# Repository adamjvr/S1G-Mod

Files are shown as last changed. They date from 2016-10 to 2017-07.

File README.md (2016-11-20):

# S1G-Mod
A Sub 1GHZ Wireless Module for various Sub 1GHZ projects and applications
Hardware Specs
- ADF7023 RF Transceiver
- 28 Mile line of site range
- Dedicated Antennas for RX and TX
- Open Source under CERN Open Hardware License v1.2 (Included)
- Circuitry shielded with outer shield.
- UM Coaxial Antenna connectors
- STM32L052C8T6 ARM Cortex M0+
- USB 2.0 connectivity
- USART connectivity
- SPI connectivity
- USB bus or battery powered
- Combined and Separate PA/LNA Match versions of 915MHZ and 433MHZ modules

Firmware and development at:
https://github.com/adamjvr/S1G-RF-firmwware

Combined RX/TX S1G-RF Module:
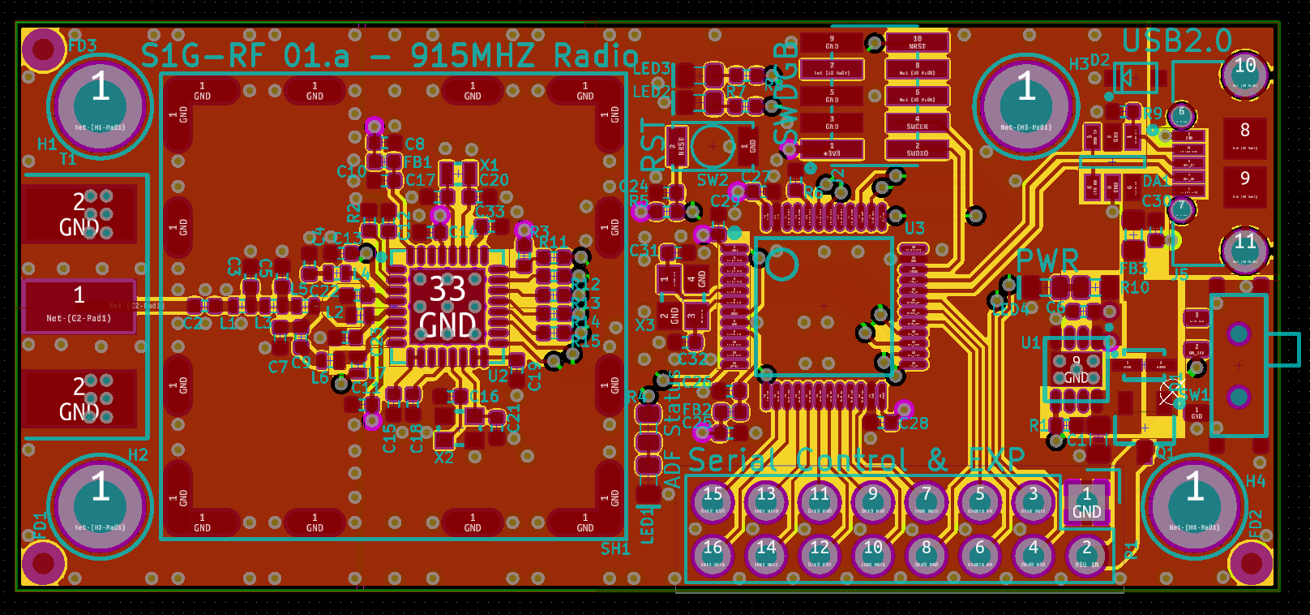
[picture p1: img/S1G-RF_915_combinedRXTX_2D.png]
Combined RX/TX S1G-RF

KiCAD 3D OpenGL
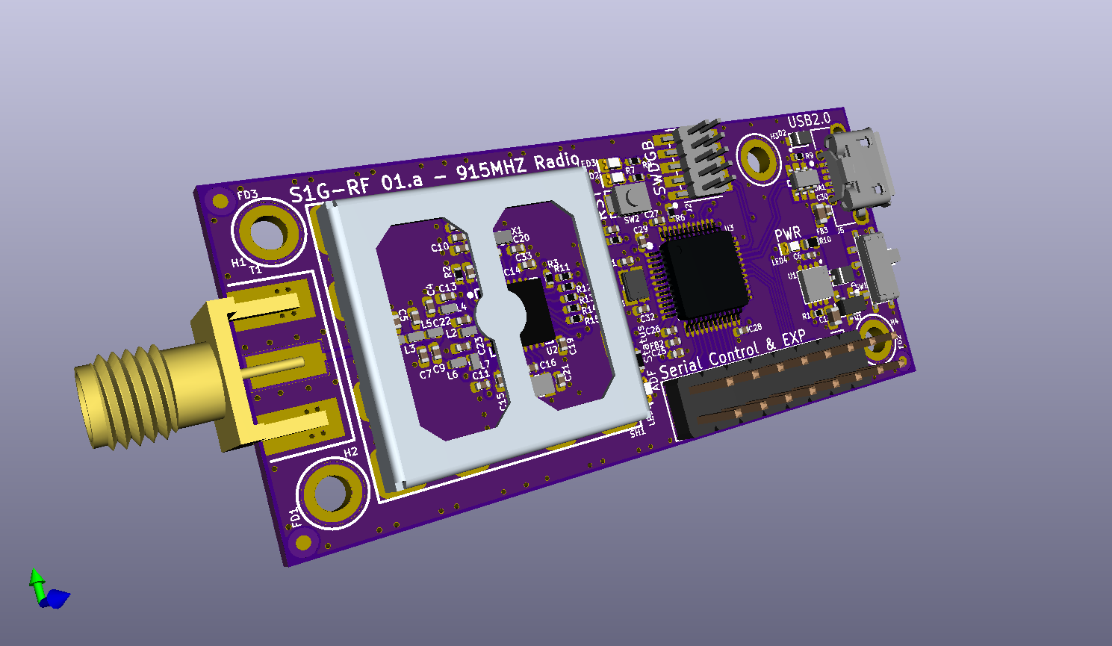
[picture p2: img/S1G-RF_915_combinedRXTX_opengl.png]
Combined RX/TX S1G-RF 3D


Separate RX/TX S1G-RF Module:
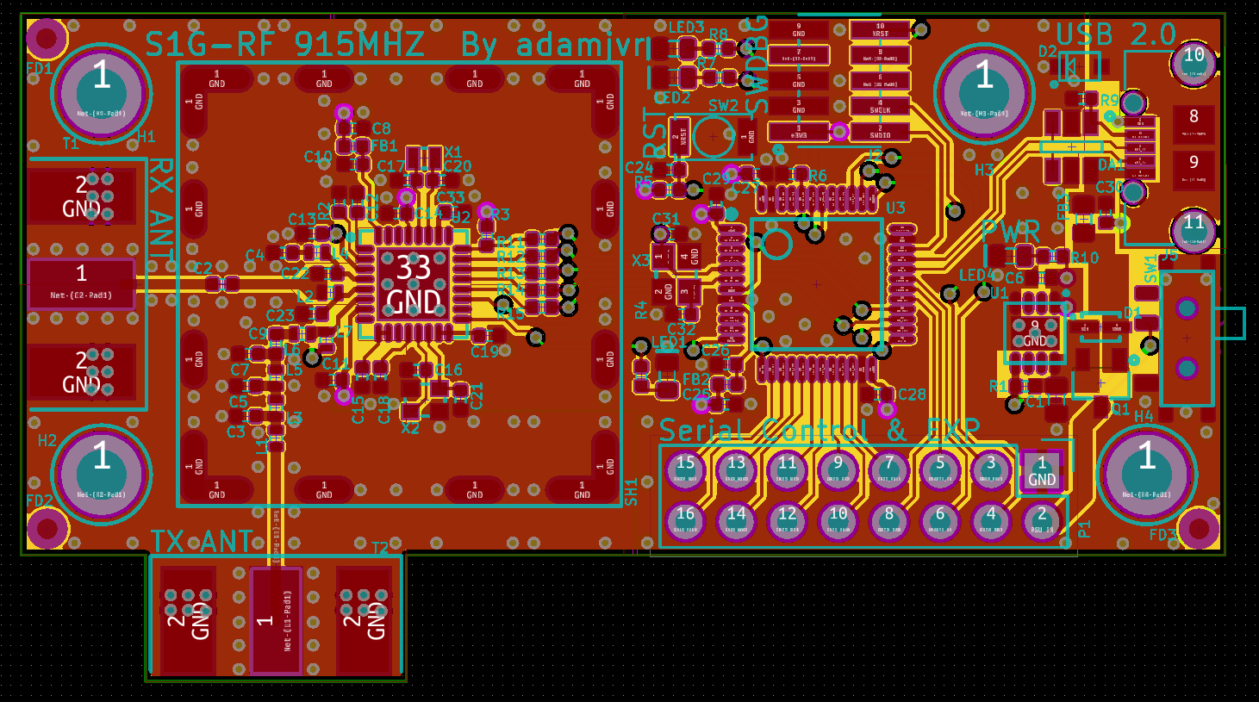
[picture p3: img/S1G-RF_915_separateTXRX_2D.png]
Separate RX/TX S1G-RF

KiCAD 3D OpenGL
Separate RX/TX S1G-RF 3D

Adapters:

USART JST Adapter
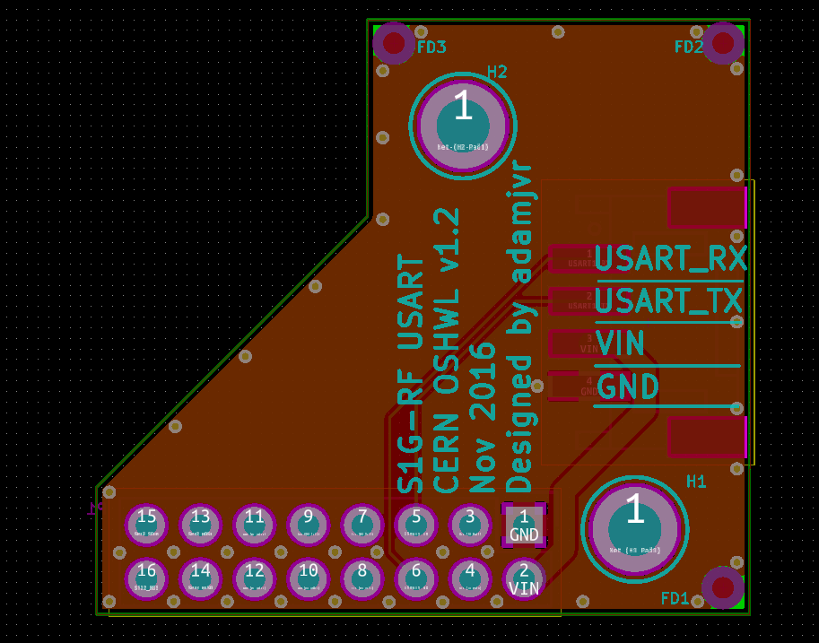
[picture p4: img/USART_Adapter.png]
USART Adapter

SPI JST Adapter
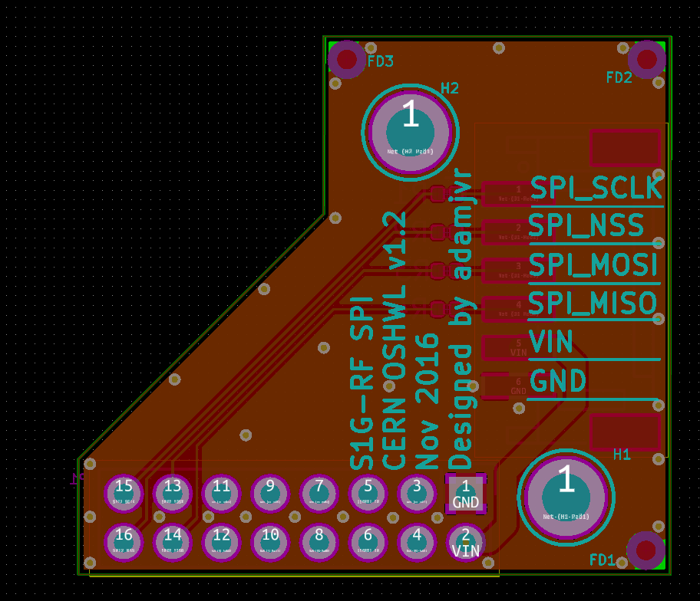
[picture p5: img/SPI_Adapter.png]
SPI Adapter


Adapter Test Fit:
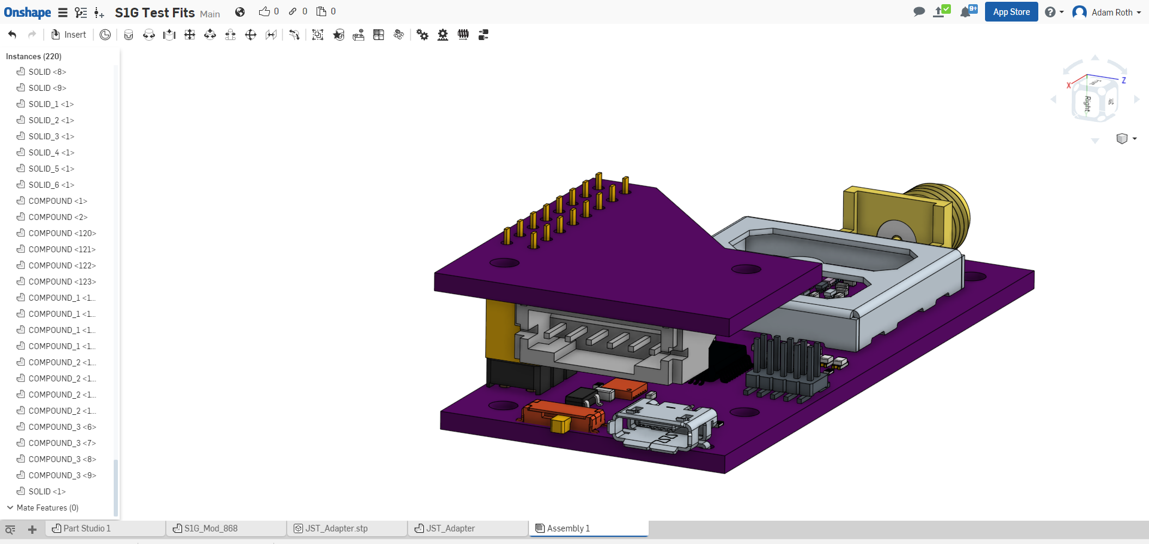
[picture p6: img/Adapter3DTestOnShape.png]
Adapter Test Fit CAD


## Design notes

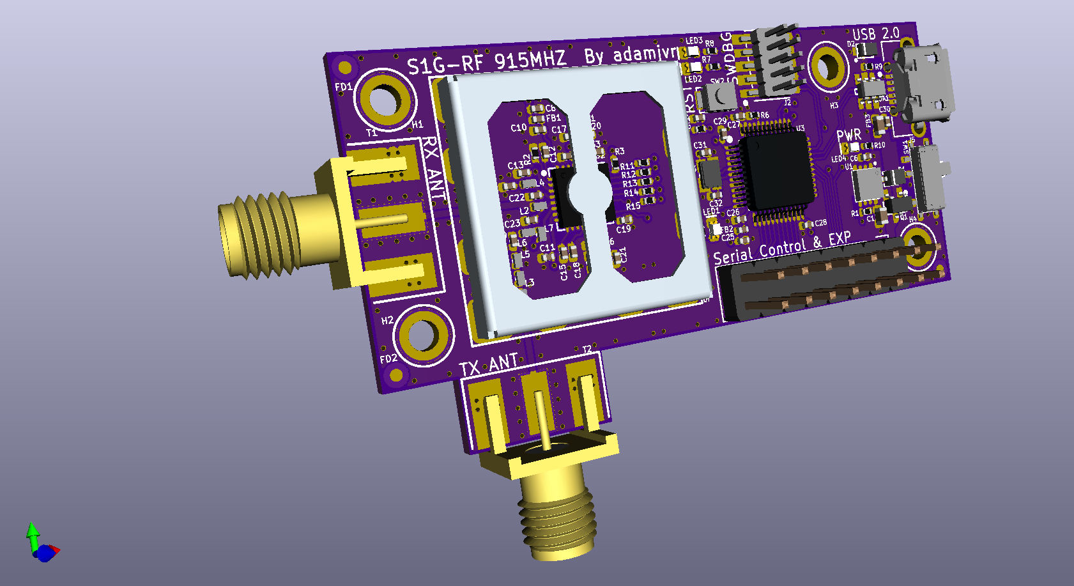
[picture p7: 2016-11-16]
img/S1G-RF_915_separateTXRX_opengl.png

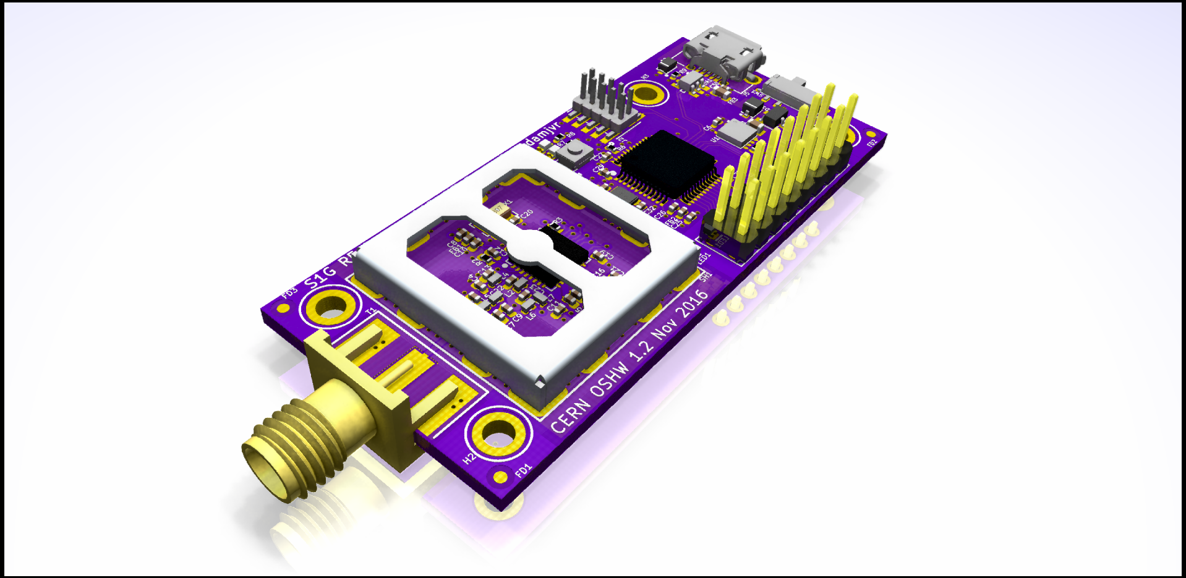
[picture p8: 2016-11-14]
PCB_868_900_Combined/S1G_915MHZ.png

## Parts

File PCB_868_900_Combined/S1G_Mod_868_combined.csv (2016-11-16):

Id | Designator | Package | Quantity | Designation | Supplier and ref
1 | R15,R14,R13,R12,R11 | R0402 | 5 | TNPW0402100RBEED
2 | LED4 | LED0603 | 1 | LTST-C193KRKT-5A
3 | R10,R4 | R0603 | 2 | RC1608J202CS
4 | FD4,FD5,FD6,FD1,FD2,FD3 | FIDUCIAL | 6 | FIDUCIAL
5 | P1 | 61301621121 | 1 | 61301621121
6 | X1 | ABS05-32.768KHZ-9-T | 1 | ABS05-32.768KHZ-9-T
7 | C33,C13,C19,C15,C12 | C0402 | 5 | CL10B224JO8NNNC
8 | T1 | 0732511150 | 1 | 0732511150
9 | SH1 | 36103205 | 1 | 36103205
10 | U3 | STM32L052C8T6 | 1 | STM32L052C8T6
11 | U1 | AP7361-33FGE-7 | 1 | AP7361-33FGE-7
12 | U2 | ADF7023BCPZ | 1 | ADF7023BCPZ
13 | X3 | ABM10-166-12.000MHZ-T3 | 1 | ABM10-166-12.000MHZ-T3
14 | C31,C32,C16,C21 | C0402 | 4 | GRM0225C1E8R0WA03L
15 | SW2 | B3U-1000P | 1 | B3U-1000P
16 | J5 | 0475890001 | 1 | 0475890001-MicroUSBPort
17 | J2 | 20021121-00010C4LF | 1 | 20021121-00010C4LF
18 | D1 | BAT20JFILM | 1 | BAT20JFILM
19 | FB2,FB1 | BLM15HG601SN1D | 2 | BLM15HG601SN1D
20 | C30,C29,C28,C27,C26,C25,C24,C6,C10,C14,C8,C11 | C0402 | 12 | CL05B104JP5NNNC
21 | SW1 | CUS-12TB | 1 | CUS-12TB
22 | Q1 | DMG2307L-7 | 1 | DMG2307L-7
23 | DA1 | ESDA6V1BC6 | 1 | ESDA6V1BC6
24 | LED2,LED1 | LED0603 | 2 | LTST-C193TBKT-5A
25 | LED3 | LED0603 | 1 | LTST-C191KGKT
26 | H4,H3,H2,H1 | M2.5_HOLE | 4 | M2.5_Hole
27 | FB3 | MI0603K300R-10 | 1 | MI0603K300R-10
28 | R5,R7,R8 | R0402 | 3 | RC1005F102CS
29 | R6,R1,R3 | R0402 | 3 | RC1005F103CS
30 | R9 | R0402 | 1 | RC1005J473CS
31 | D2 | RSB39VTE-17 | 1 | RSB39VTE-17
32 | R2 | R0402 | 1 | ERA-2AEB363X
33 | X2 | ABM11-140-26.000MHZ-T3 | 1 | ABM11-140-26.000MHZ-T3
34 | C22 | C0402 | 1 | GRM1555C2A2R7CA01D
35 | C23 | C0402 | 1 | GRM1555C1E1R2BA01D
36 | C20,C17 | C0402 | 2 | CL05C090CB5NNNC
37 | C18 | C0402 | 1 | GRM155R71H152KA01D
38 | C7 | C0402 | 1 | GJM1555C1H1R0BB01D
39 | C2 | C0402 | 1 | CBR04C560F1GAC
40 | C3,C5 | C0402 | 2 | GJM1555C1H2R2WB01D
41 | C4 | C0402 | 1 | GRM1555C1H101GA01D
42 | C9 | C0402 | 1 | CBR04C470F3GAC
43 | C1 | C0603 | 1 | CL10A106KQ8NNNC
44 | L1,L2,L5 | L0402 | 3 | 0402CS-12NXJL
45 | L3 | L0402 | 1 | 0402CS-24NXJL
46 | L4 | L0402 | 1 | 0402CS-6N2XJL
47 | L6 | L0402 | 1 | 0402CS-1N8XJL
48 | L7 | L0402 | 1 | 0402CS-47NXJL

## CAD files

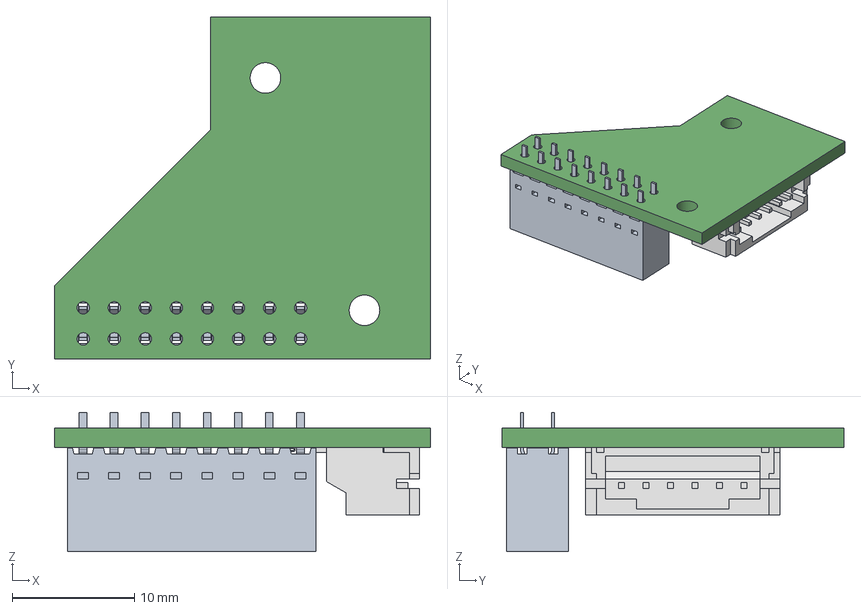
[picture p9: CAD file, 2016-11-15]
Adapters/JST/PCB/JST_Adapter.stp
30.8 x 28.0 x 11.4 mm

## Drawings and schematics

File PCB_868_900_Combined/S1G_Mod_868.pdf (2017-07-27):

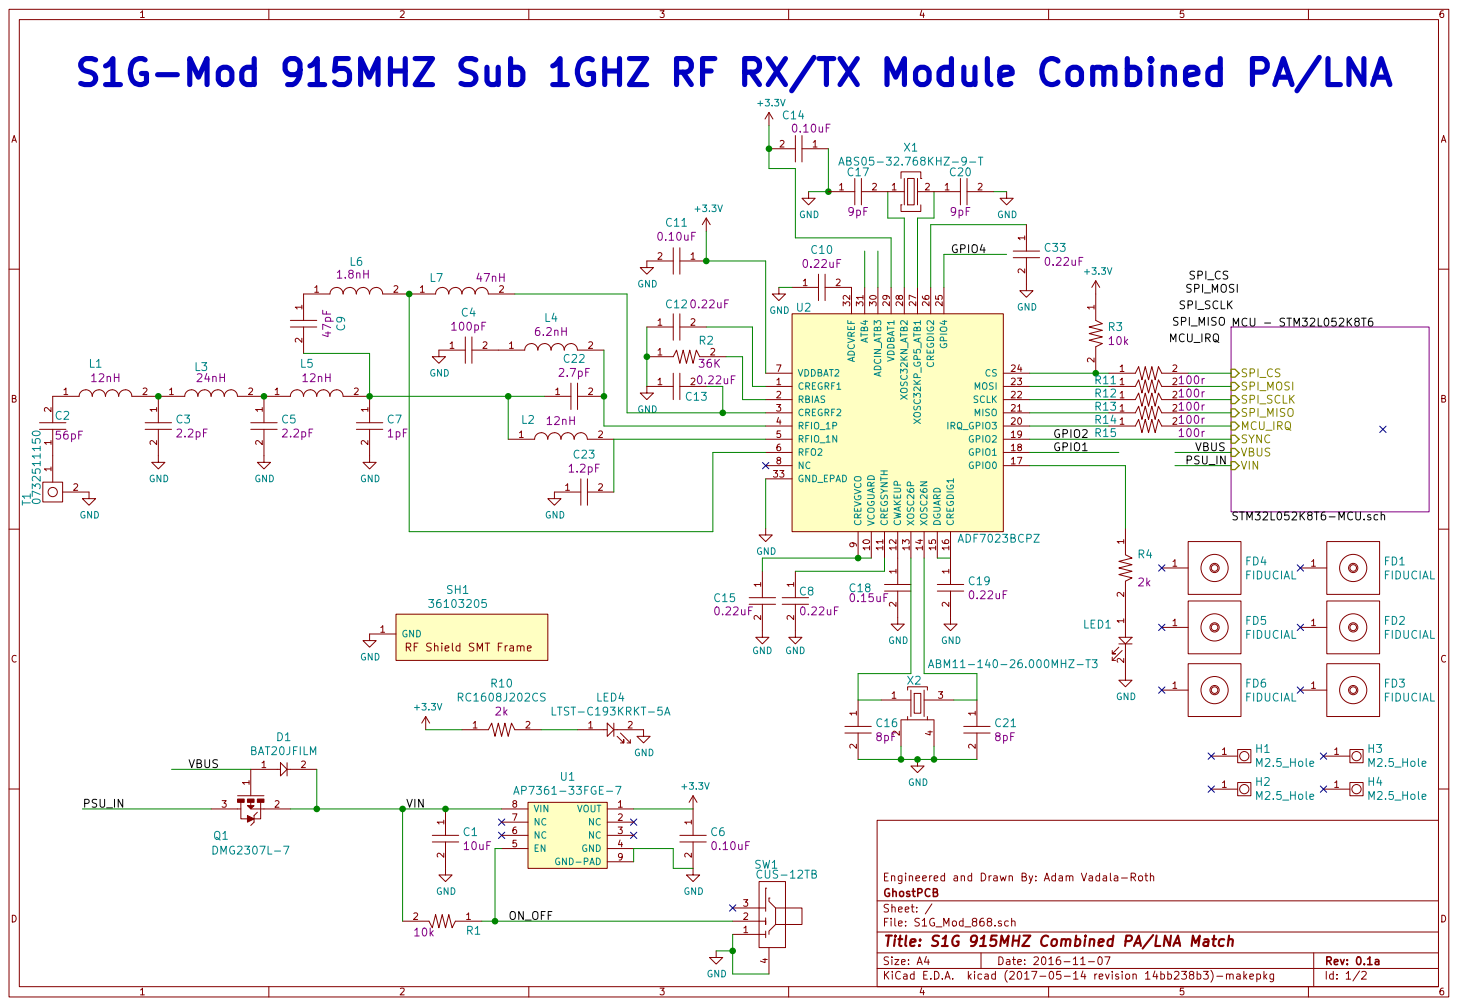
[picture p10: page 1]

56pFGND S1G-Mod 915MHZ Sub 1GHZ RF RX/TX Module Combined PA/LNA

Engineered and Drawn By: Adam Vadala-Roth
File: S1G_Mod_868.sch Sheet: / GhostPCB

Id: 1/2 Title: S1G 915MHZ Combined PA/LNA Match

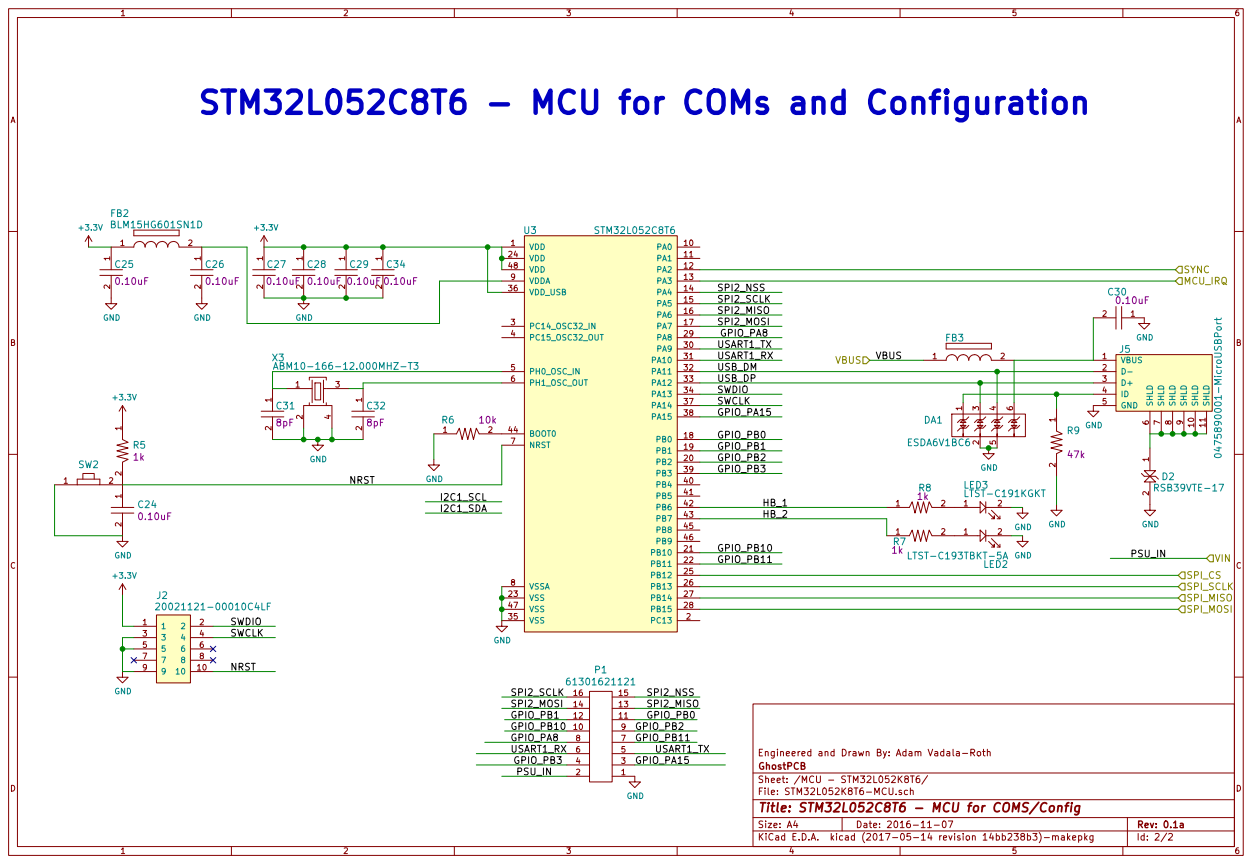
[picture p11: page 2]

STM32L052C8T6 - MCU for COMs and Configuration

SPI2_SCLK
SPI2_MISO

9 SHLD 10 SHLD 11 J5 0475890001-MicroUSBPort GND

USB_DP
SWDIO

14 | | 13
12 | | | 11
10 | | 9

Engineered and Drawn By: Adam Vadala-Roth
File: STM32L052K8T6-MCU.sch Sheet: /MCU - STM32L052K8T6/ GhostPCB

Id: 2/2 Title: STM32L052C8T6 - MCU for COMS/Config

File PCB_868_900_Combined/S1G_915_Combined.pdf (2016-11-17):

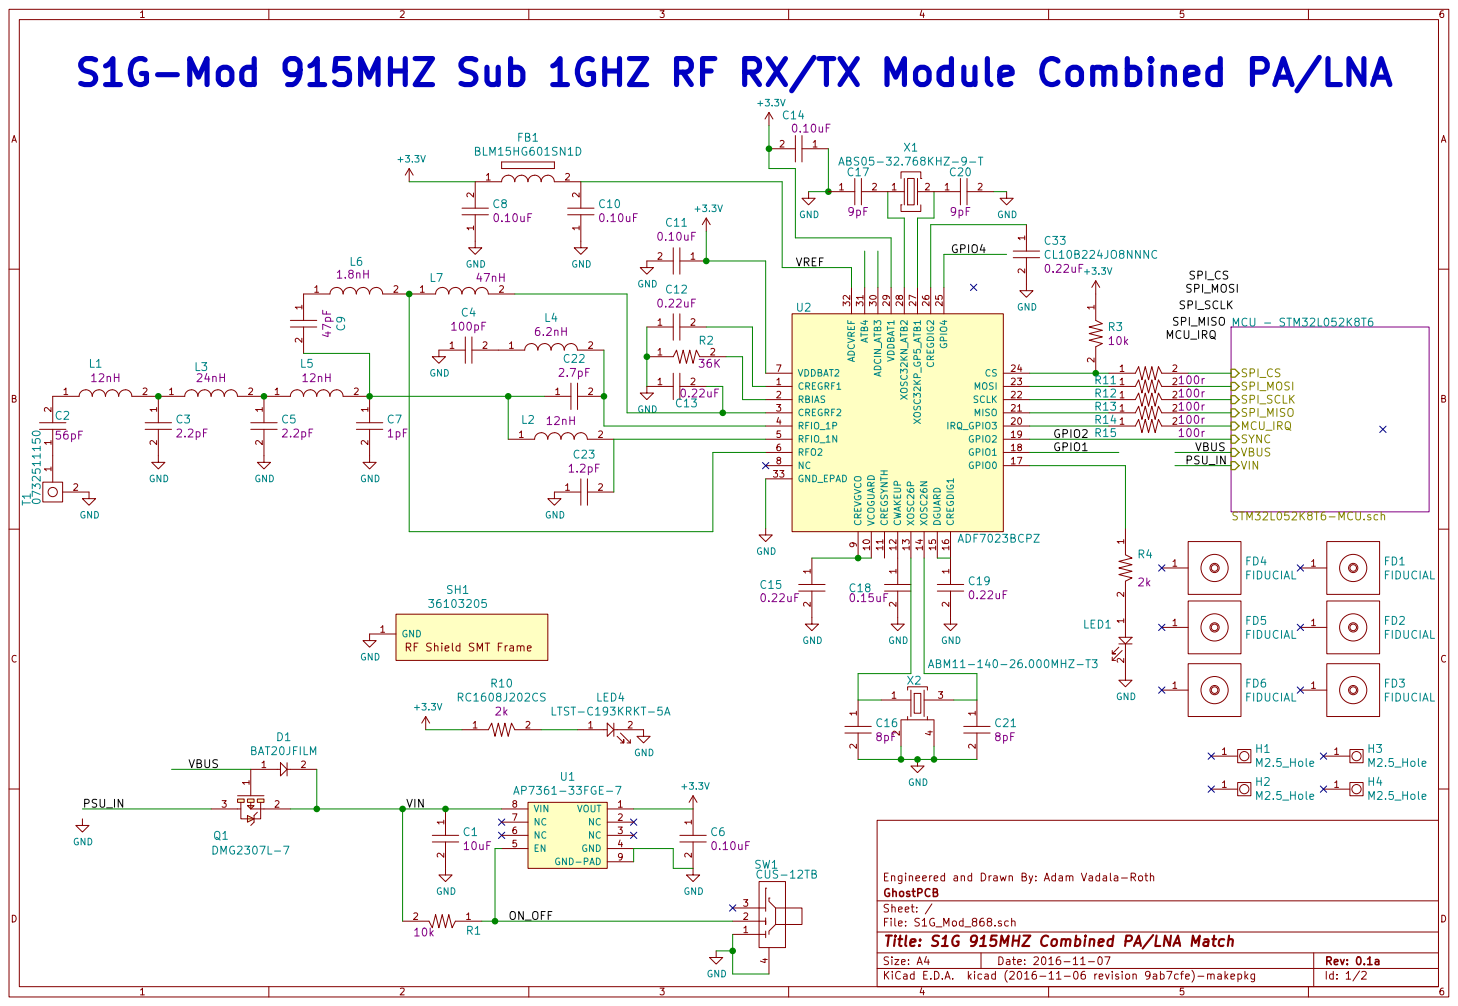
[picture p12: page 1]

56pFGND S1G-Mod 915MHZ Sub 1GHZ RF RX/TX Module Combined PA/LNA

Engineered and Drawn By: Adam Vadala-Roth
File: S1G_Mod_868.sch Sheet: / GhostPCB

Id: 1/2 Title: S1G 915MHZ Combined PA/LNA Match

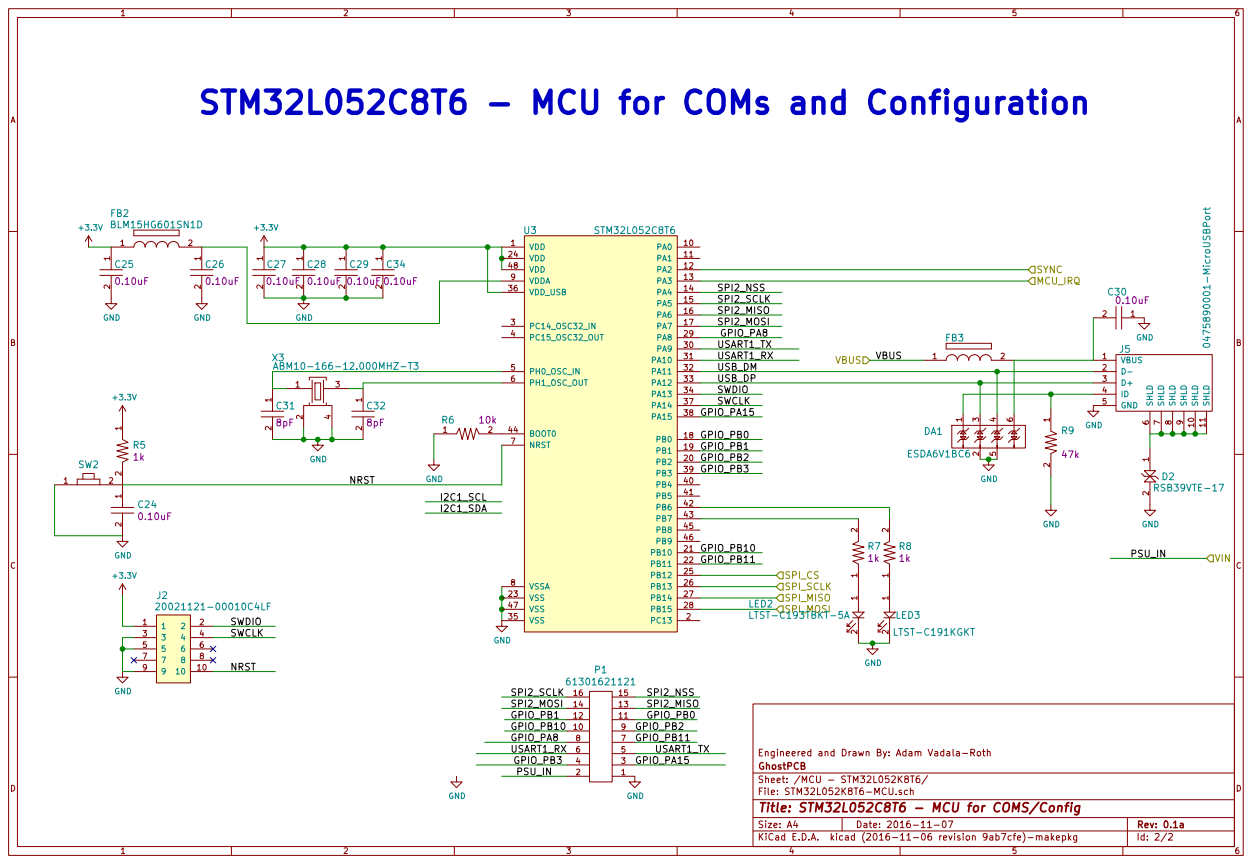
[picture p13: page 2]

STM32L052C8T6 - MCU for COMs and Configuration

9 SHLD 10 SHLD 11 J5 0475890001-MicroUSBPort GND

SPI2_SCLK
SPI2_MISO

USB_DP
SWDIO

14 | | 13
12 | | | 11
10 | | 9

Engineered and Drawn By: Adam Vadala-Roth
File: STM32L052K8T6-MCU.sch Sheet: /MCU - STM32L052K8T6/ GhostPCB

Id: 2/2 Title: STM32L052C8T6 - MCU for COMS/Config

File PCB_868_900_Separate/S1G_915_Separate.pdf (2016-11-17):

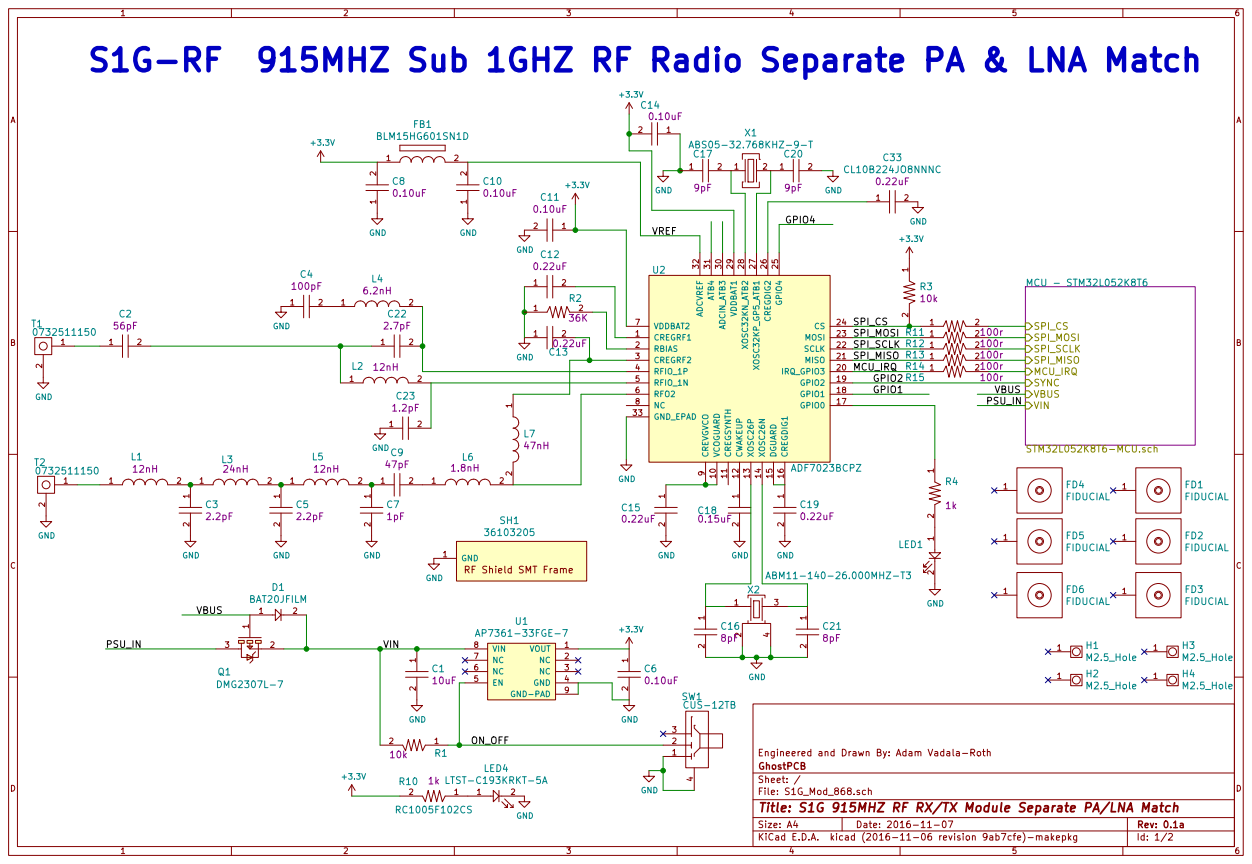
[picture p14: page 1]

SPI_MOSI
SPI_SCLK
SPI_MISO

Engineered and Drawn By: Adam Vadala-Roth
File: S1G_Mod_868.sch Sheet: / GhostPCB

Id: 1/2 Title: S1G 915MHZ RF RX/TX Module Separate PA/LNA Match

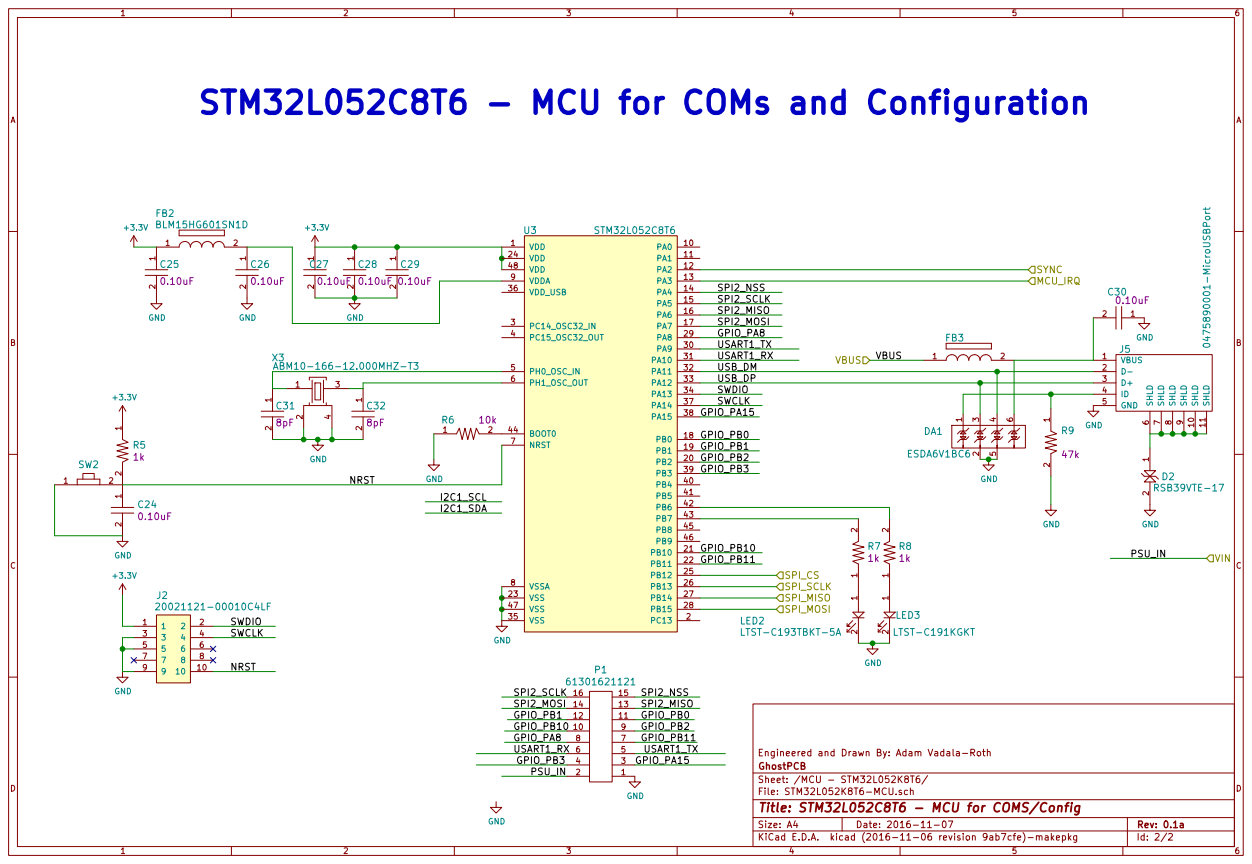
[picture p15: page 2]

STM32L052C8T6 - MCU for COMs and Configuration

9 SHLD 10 SHLD 11 J5 0475890001-MicroUSBPort GND

SPI2_SCLK
SPI2_MISO

USB_DP
SWDIO

Engineered and Drawn By: Adam Vadala-Roth
File: STM32L052K8T6-MCU.sch Sheet: /MCU - STM32L052K8T6/ GhostPCB

Id: 2/2 Title: STM32L052C8T6 - MCU for COMS/Config

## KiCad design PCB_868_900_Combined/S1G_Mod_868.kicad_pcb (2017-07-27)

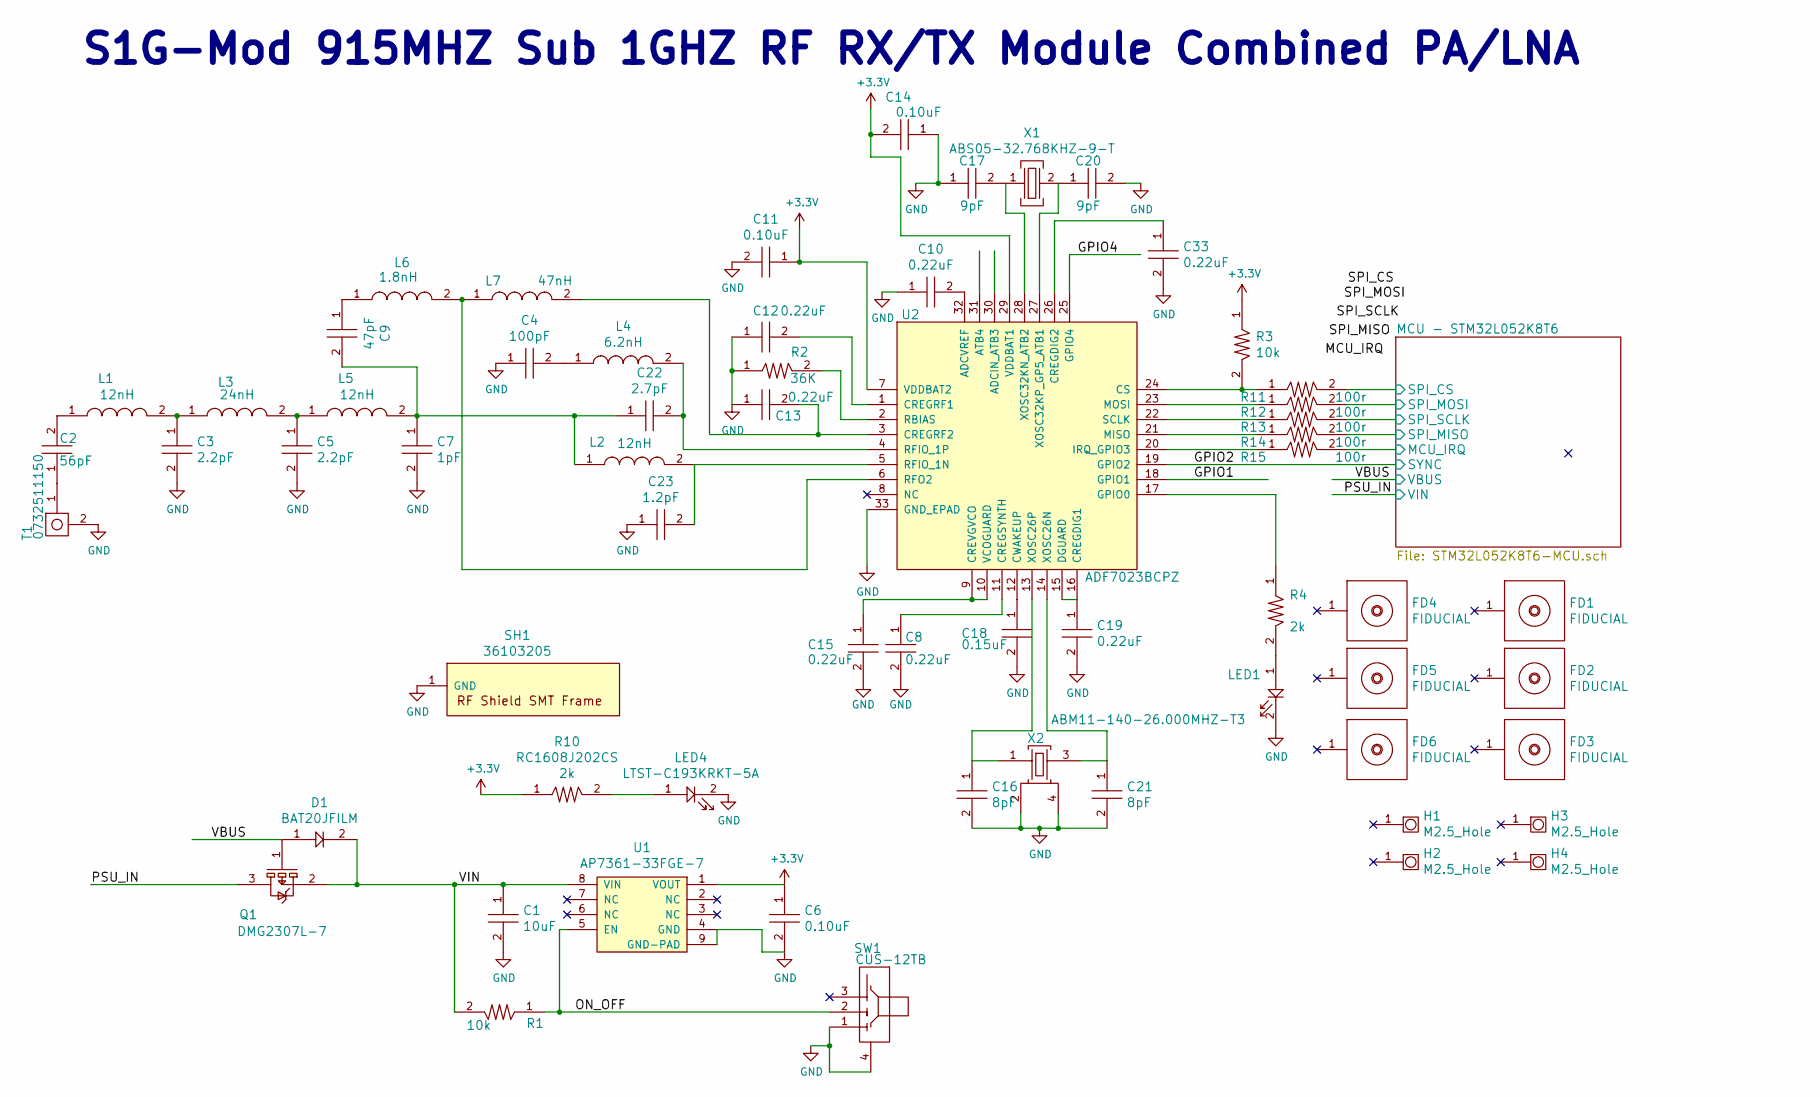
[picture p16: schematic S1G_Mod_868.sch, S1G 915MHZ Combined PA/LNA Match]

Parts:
C1: CL10A106KQ8NNNC; C0603; Tolerance 10%; Voltage 6.3V; MFR# CL10A106KQ8NNNC
C2: CBR04C560F1GAC; C0402; Tolerance 1%; Voltage 100V; MFR# CBR04C560F1GAC
C3, C5: GJM1555C1H2R2WB01D; C0402; Tolerance 0.05pF; Voltage 50V; MFR# GJM1555C1H2R2WB01D
C4: GRM1555C1H101GA01D; C0402; Tolerance 2%; Voltage 50V; MFR# GRM1555C1H101GA01D
C6, C11, C14: CL05B104JP5NNNC; C0402; Tolerance 5%; Voltage 10V; MFR# CL05B104JP5NNNC
C7: GJM1555C1H1R0BB01D; C0402; Tolerance 0.1pF; Voltage 50V; MFR# GJM1555C1H1R0BB01D
C8, C10, C12, C13, C15, C19, C33: CL05A224KP5NNNC; C0402; Tolerance 0.22uF; Voltage 16V; MFR# CL05A224KP5NNNC
C9: CBR04C470F3GAC; C0402; Tolerance 1%; Voltage 25V; MFR# CBR04C470F3GAC
C16, C21: GRM0225C1E8R0WA03L; C0402; Tolerance 0.05pF; Voltage 50V; MFR# GRM0225C1E8R0WA03L
C17, C20: CL05C090CB5NNNC; C0402; Tolerance 0.25pF; Voltage 50V; MFR# CL05C090CB5NNNC
C18: GRM155R71H152KA01D; C0402; Tolerance 10%; Voltage 50V; MFR# GRM155R71H152KA01D
C22: GRM1555C2A2R7CA01D; C0402; Tolerance 0.25pF; Voltage 50V; MFR# GRM1555C2A2R7CA01D
C23: GRM1555C1E1R2BA01D; C0402; Tolerance 0.1pF; Voltage 25V; MFR# GRM1555C1E1R2BA01D
D1: BAT20JFILM; Tolerance N/A; Voltage N/A; MFR# BAT20JFILM
FD1, FD2, FD3, FD4, FD5, FD6: FIDUCIAL
H1, H2, H3, H4: M2.5_Hole; M2.5_HOLE
L1, L2, L5: 0402CS-12NXJL; L0402; Tolerance 5%; Voltage N/A; MFR# 0402CS-12NXJL
L3: 0402CS-24NXJL; L0402; Tolerance 5%; Voltage N/A; MFR# 0402CS-24NXJL
L4: 0402CS-6N2XJL; L0402; Tolerance 5%; Voltage N/A; MFR# 0402CS-6N2XJL
L6: 0402CS-1N8XJL; L0402; Tolerance 5%; Voltage N/A; MFR# 0402CS-1N8XJL
L7: 0402CS-47NXJL; L0402; Tolerance 5%; Voltage N/A; MFR# 0402CS-47NXJL
LED1: LTST-C193TBKT-5A; LED0603; Tolerance N/A; Voltage 2.8V Forward Voltage; MFR# LTST-C193TBKT-5A
LED4: LTST-C193KRKT-5A; LED0603; Tolerance N/A; Voltage 2.8V Forward Voltage; MFR# LTST-C193KRKT-5A
Q1: DMG2307L-7; Tolerance N/A; Voltage 30V; MFR# DMG2307L-7
R1, R3: RC1005F103CS; R0402; Tolerance 1%; Voltage N/A; MFR# RC1005F103CS
R2: ERA-2AEB363X; R0402; Tolerance 0.1%; Voltage N/A; MFR# ERA-2AEB363X
R4, R10: RC1608J202CS; R0603; Tolerance 1%; Voltage N/A; MFR# RC1608F202CS
R11, R12, R13, R14, R15: TNPW0402100RBEED; R0402; Tolerance 0.1%; Voltage N/A; MFR# TNPW0402100RBEED
SH1: 36103205; Tolerance N/A; Voltage N/A; MFR# 36103205
SW1: CUS-12TB; Tolerance N/A; Voltage 50V 100mA; MFR# CUS-12TB
T1: 0732511150; Tolerance N/A; Voltage N/A; MFR# 0732511150
U1: AP7361-33FGE-7; Tolerance N/A; Voltage 3.3V; MFR# AP7361-33FGE-7
U2: ADF7023BCPZ; Tolerance N/A; Voltage 3.3V; MFR# ADF7023BCPZ
X1: ABS05-32.768KHZ-9-T; Tolerance ±20ppm; Voltage N/A; MFR# ABS05-32.768KHZ-9-T
X2: ABM11-140-26.000MHZ-T3; Tolerance N/A; Voltage N/A; MFR# ABM11-140-26.000MHZ-T3

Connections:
+3V3: C6.1, C11.1, C14.2, R3.1, R10.1, U1.1 (VOUT), U2.7 (VDDBAT2), U2.29 (VDDBAT1); also elsewhere on the board
/GPIO1: U2.18 (GPIO1)
/GPIO2: U2.19 (GPIO2); also elsewhere on the board
/GPIO4: U2.25 (GPIO4)
/MCU - STM32L052K8T6/MCU_IRQ: R15.2; also elsewhere on the board
/MCU - STM32L052K8T6/SPI_CS: R11.2; also elsewhere on the board
/MCU - STM32L052K8T6/SPI_MISO: R14.2; also elsewhere on the board
/MCU - STM32L052K8T6/SPI_MOSI: R12.2; also elsewhere on the board
/MCU - STM32L052K8T6/SPI_SCLK: R13.2; also elsewhere on the board
/ON_OFF: R1.1, SW1.2, U1.5 (EN)
/PSU_IN: Q1.3; also elsewhere on the board
/VBUS: D1.1, Q1.1; also elsewhere on the board
/VIN: C1.1, D1.2, Q1.2, R1.2, U1.8 (VIN)
GND: C1.2, C3.2, C4.1, C5.2, C6.2, C7.2, C8.2, C10.1, C11.2, C12.1, C13.1, C14.1, C15.2, C16.2, C17.1, C18.2, C19.2, C20.2, C21.2, C23.1, C33.2, LED1.2, LED4.2, R2.1, SH1.1, SW1.1, SW1.4, T1.2, U1.4 (GND), U1.9 (GND-PAD), U2.33 (GND_EPAD), X2.2, X2.4; also elsewhere on the board
unnamed: C2.1, T1.1
unnamed: C2.2, L1.1
unnamed: C3.1, L1.2, L3.1
unnamed: C4.2, L4.1
unnamed: C5.1, L3.2, L5.1
unnamed: C8.1, U2.11 (CREGSYNTH)
unnamed: C9.1, L6.1
unnamed: C10.2, U2.32 (ADCVREF)
unnamed: C12.2, U2.1 (CREGRF1)
unnamed: C13.2, L7.2, U2.3 (CREGRF2)
unnamed: C15.1, U2.9 (CREVGVCO), U2.10 (VCOGUARD)
unnamed: C16.1, U2.13 (XOSC26P), X2.1
unnamed: C17.2, U2.28 (XOSC32KN_ATB2), X1.1
unnamed: C18.1, U2.12 (CWAKEUP)
unnamed: C19.1, U2.15 (DGUARD), U2.16 (CREGDIG1)
unnamed: C20.1, U2.27 (XOSC32KP_GP5_ATB1), X1.2
unnamed: C21.1, U2.14 (XOSC26N), X2.3
unnamed: C7.1, C9.2, C22.1, L2.1, L5.2
unnamed: C22.2, L4.2, U2.4 (RFIO_1P)
unnamed: C23.2, L2.2, U2.5 (RFIO_1N)
unnamed: C33.1, U2.26 (CREGDIG2)
unnamed: L6.2, L7.1, U2.6 (RFO2)
unnamed: LED1.1, R4.2
unnamed: LED4.1, R10.2
unnamed: R2.2, U2.2 (RBIAS)
unnamed: R4.1, U2.17 (GPIO0)
unnamed: R3.2, R11.1, U2.24 (CS)
unnamed: R12.1, U2.23 (MOSI)
unnamed: R13.1, U2.22 (SCLK)
unnamed: R14.1, U2.21 (MISO)
unnamed: R15.1, U2.20 (IRQ_GPIO3)

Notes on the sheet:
S1G-Mod 915MHZ Sub 1GHZ RF RX/TX Module Combined PA/LNA

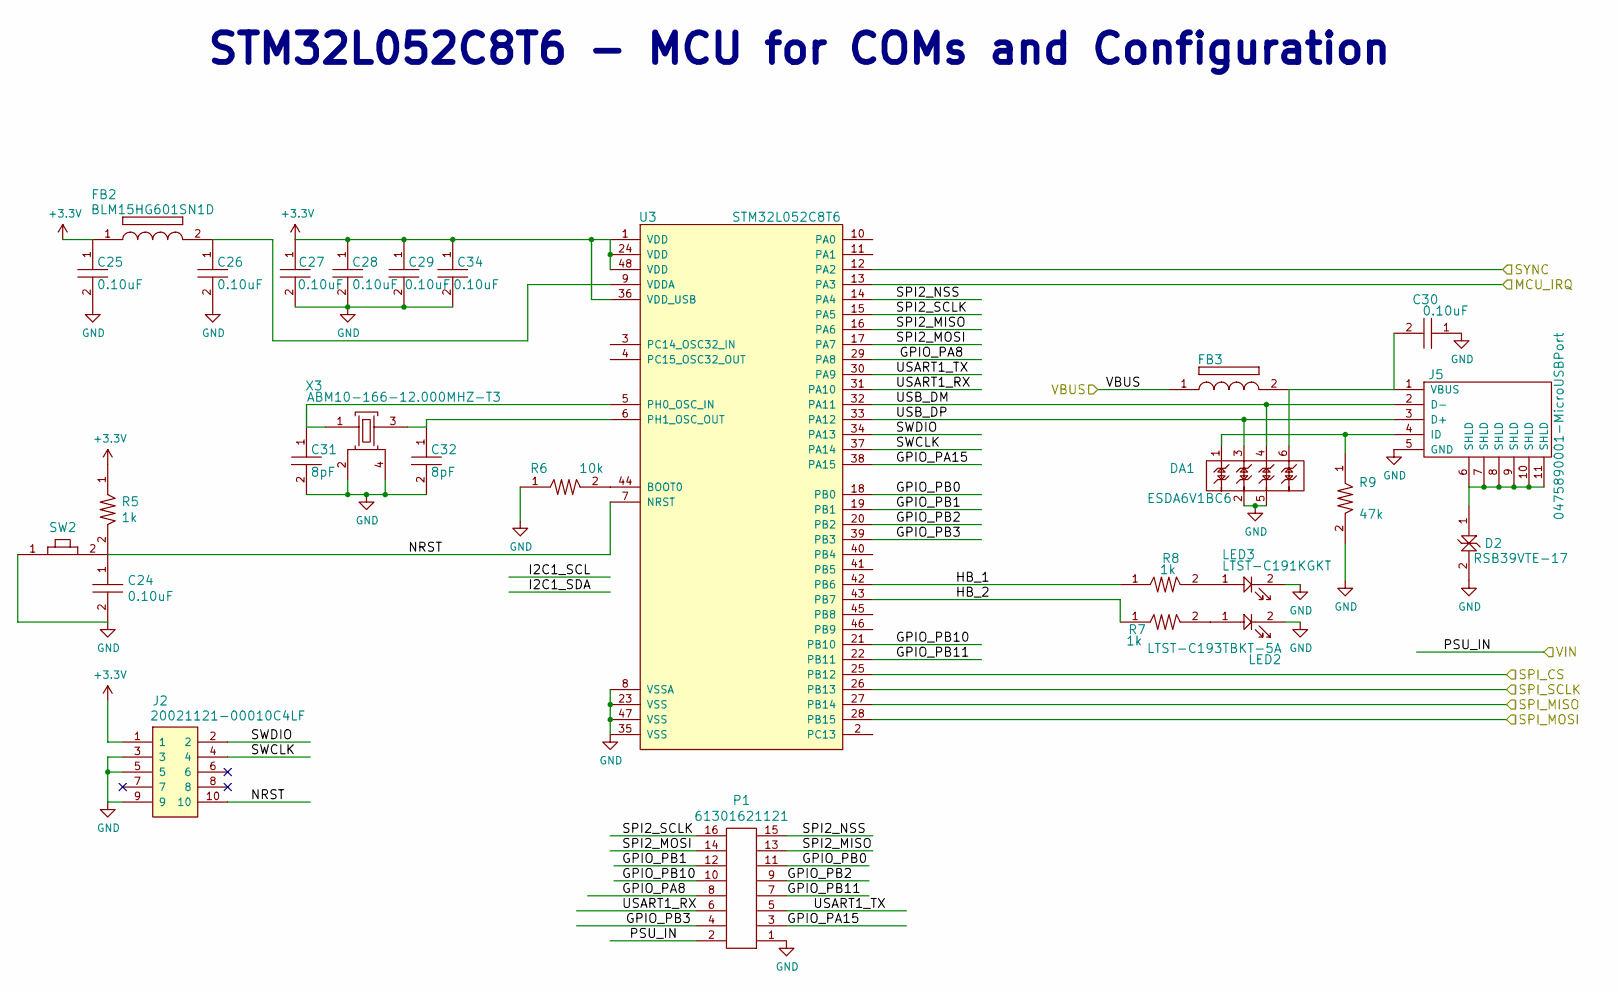
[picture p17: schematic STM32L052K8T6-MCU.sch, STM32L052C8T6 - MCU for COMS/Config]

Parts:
C24, C25, C26, C27, C28, C29, C30, C34: CL05B104JP5NNNC; C0402; Tolerance 5%; Voltage 10V; MFR# CL05B104JP5NNNC
C31, C32: GRM0225C1E8R0WA03L; C0402; Tolerance 0.05pF; Voltage 50V; MFR# GRM0225C1E8R0WA03L
D2: RSB39VTE-17; Tolerance N/A; Voltage 30V; MFR# RSB39VTE-17
DA1: ESDA6V1BC6; Tolerance N/A; Voltage 4V; MFR# ESDA6V1BC6
FB2: BLM15HG601SN1D; Tolerance N/A; Voltage N/A; MFR# BLM15HG601SN1D
FB3: MI0603K300R-10; Tolerance N/A; Voltage N/A; MFR# MI0603K300R-10
J2: 20021121-00010C4LF; Tolerance N/A; Voltage 200V MAX; MFR# 20021121-00010C4LF
J5: 0475890001-MicroUSBPort; 0475890001; Tolerance N/A; Voltage 5V; MFR# 0475890001
LED2: LTST-C193TBKT-5A; LED0603; Tolerance N/A; Voltage 2.8V Forward Voltage; MFR# LTST-C193TBKT-5A
LED3: LTST-C191KGKT; LED0603; Tolerance N/A; Voltage N/A; MFR# LTST-C191KGKT
P1: 61301621121; Tolerance N/A; Voltage N/A; MFR# B3B-PH-SM4-TB(LF)(SN)
R5, R7, R8: RC1005F102CS; R0402; Tolerance %; Voltage N/A; MFR# RC1005F102CS
R6: RC1005F103CS; R0402; Tolerance 1%; Voltage N/A; MFR# RC1005F103CS
R9: RC1005J473CS; R0402; Tolerance 5%; Voltage N/A; MFR# RC1005J473CS
SW2: B3U-1000P; Tolerance %; Voltage 50V; MFR# B3U-1000P
U3: STM32L052C8T6; Tolerance N/A; Voltage 1.8-3.3V; MFR# STM32L052C8T6
X3: ABM10-166-12.000MHZ-T3; Tolerance N/A; Voltage N/A; MFR# ABM10-166-12.000MHZ-T3

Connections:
+3V3: C25.1, C27.1, C28.1, C29.1, C34.1, FB2.1, J2.1, R5.1, U3.1 (VDD), U3.24 (VDD), U3.36 (VDD_USB), U3.48 (VDD); also elsewhere on the board
/GPIO2: U3.12 (PA2); also elsewhere on the board
/MCU - STM32L052K8T6/GPIO_PA8: P1.8, U3.29 (PA8)
/MCU - STM32L052K8T6/GPIO_PA15: P1.3, U3.38 (PA15)
/MCU - STM32L052K8T6/GPIO_PB0: P1.11, U3.18 (PB0)
/MCU - STM32L052K8T6/GPIO_PB1: P1.12, U3.19 (PB1)
/MCU - STM32L052K8T6/GPIO_PB2: P1.9, U3.20 (PB2)
/MCU - STM32L052K8T6/GPIO_PB3: P1.4, U3.39 (PB3)
/MCU - STM32L052K8T6/GPIO_PB10: P1.10, U3.21 (PB10)
/MCU - STM32L052K8T6/GPIO_PB11: P1.7, U3.22 (PB11)
/MCU - STM32L052K8T6/HB_1: R8.1, U3.42 (PB6)
/MCU - STM32L052K8T6/HB_2: R7.1, U3.43 (PB7)
/MCU - STM32L052K8T6/MCU_IRQ: U3.13 (PA3); also elsewhere on the board
/MCU - STM32L052K8T6/NRST: C24.1, J2.10, R5.2, SW2.2, U3.7 (NRST)
/MCU - STM32L052K8T6/SPI2_MISO: P1.13, U3.16 (PA6)
/MCU - STM32L052K8T6/SPI2_MOSI: P1.14, U3.17 (PA7)
/MCU - STM32L052K8T6/SPI2_NSS: P1.15, U3.14 (PA4)
/MCU - STM32L052K8T6/SPI2_SCLK: P1.16, U3.15 (PA5)
/MCU - STM32L052K8T6/SPI_CS: U3.25 (PB12); also elsewhere on the board
/MCU - STM32L052K8T6/SPI_MISO: U3.27 (PB14); also elsewhere on the board
/MCU - STM32L052K8T6/SPI_MOSI: U3.28 (PB15); also elsewhere on the board
/MCU - STM32L052K8T6/SPI_SCLK: U3.26 (PB13); also elsewhere on the board
/MCU - STM32L052K8T6/SWCLK: J2.4, U3.37 (PA14)
/MCU - STM32L052K8T6/SWDIO: J2.2, U3.34 (PA13)
/MCU - STM32L052K8T6/USART1_RX: P1.6, U3.31 (PA10)
/MCU - STM32L052K8T6/USART1_TX: P1.5, U3.30 (PA9)
/MCU - STM32L052K8T6/USB_DM: DA1.4, J5.2 (D-), U3.32 (PA11)
/MCU - STM32L052K8T6/USB_DP: DA1.3, J5.3 (D+), U3.33 (PA12)
/PSU_IN: P1.2; also elsewhere on the board
/VBUS: FB3.1; also elsewhere on the board
GND: C24.2, C25.2, C26.2, C27.2, C28.2, C29.2, C30.1, C31.2, C32.2, C34.2, D2.2, DA1.2, DA1.5, J2.3, J2.5, J2.9, J5.5 (GND), LED2.2, LED3.2, P1.1, R6.1, R9.2, SW2.1, U3.8 (VSSA), U3.23 (VSS), U3.35 (VSS), U3.47 (VSS), X3.2, X3.4; also elsewhere on the board
unnamed: C26.1, FB2.2, U3.9 (VDDA)
unnamed: C30.2, DA1.6, FB3.2, J5.1 (VBUS)
unnamed: C31.1, U3.5 (PH0_OSC_IN), X3.1
unnamed: C32.1, U3.6 (PH1_OSC_OUT), X3.3
unnamed: D2.1, J5.6 (SHLD), J5.7 (SHLD), J5.8 (SHLD), J5.9 (SHLD), J5.10 (SHLD), J5.11 (SHLD)
unnamed: DA1.1, J5.4 (ID), R9.1
unnamed: LED2.1, R7.2
unnamed: LED3.1, R8.2
unnamed: R6.2, U3.44 (BOOT0)

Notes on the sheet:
STM32L052C8T6 - MCU for COMs and Configuration

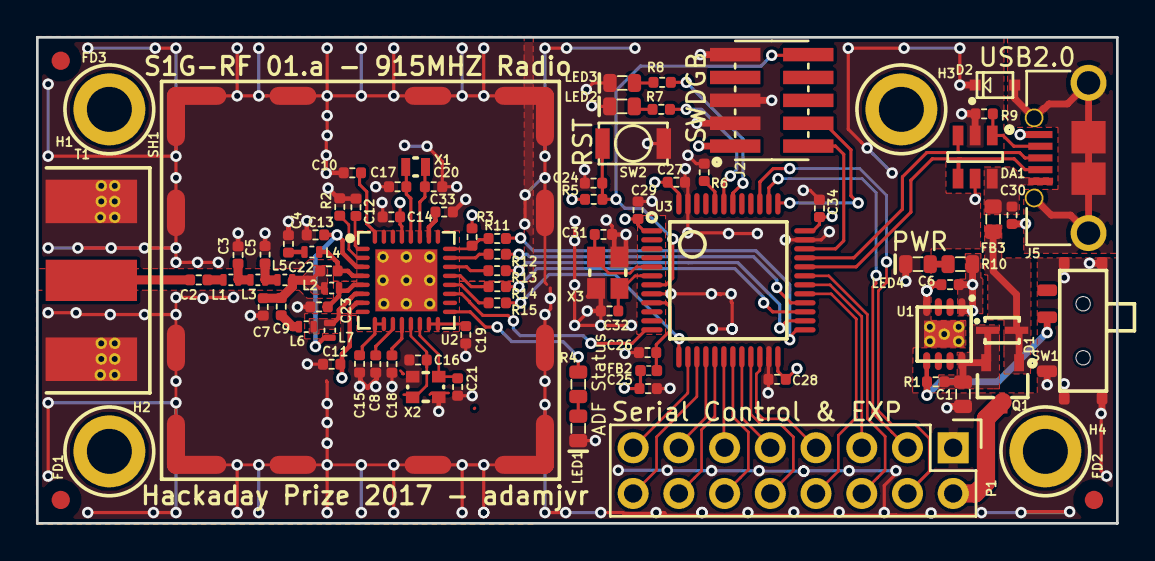
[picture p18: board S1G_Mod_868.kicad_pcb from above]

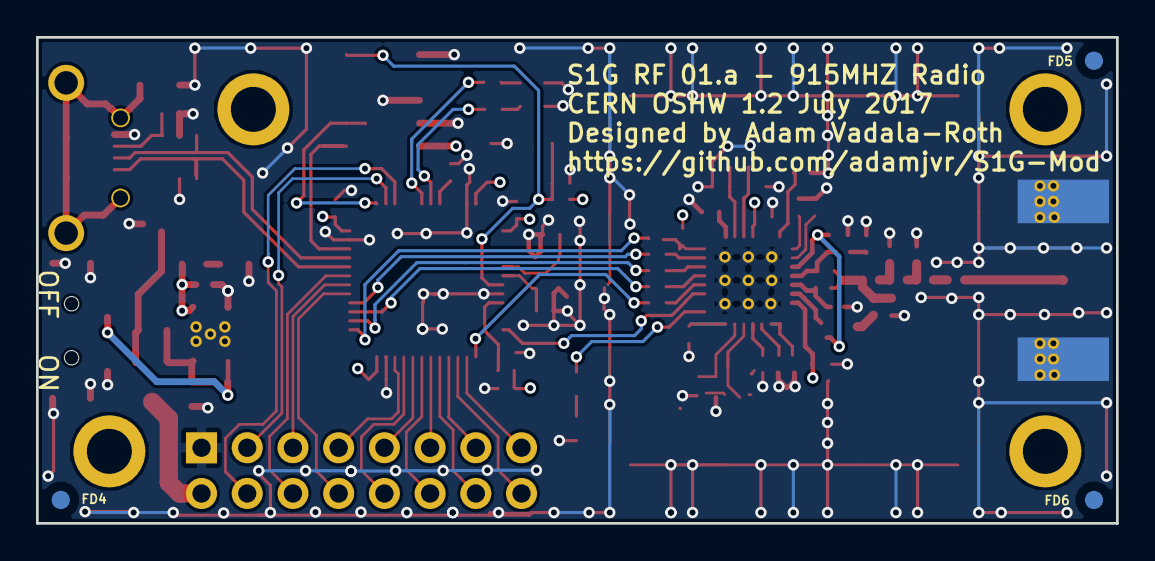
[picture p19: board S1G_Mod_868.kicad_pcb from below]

Board: 4 copper layers, 60.0 x 27.0 mm, 89 parts (3 on the bottom side), 73 nets.

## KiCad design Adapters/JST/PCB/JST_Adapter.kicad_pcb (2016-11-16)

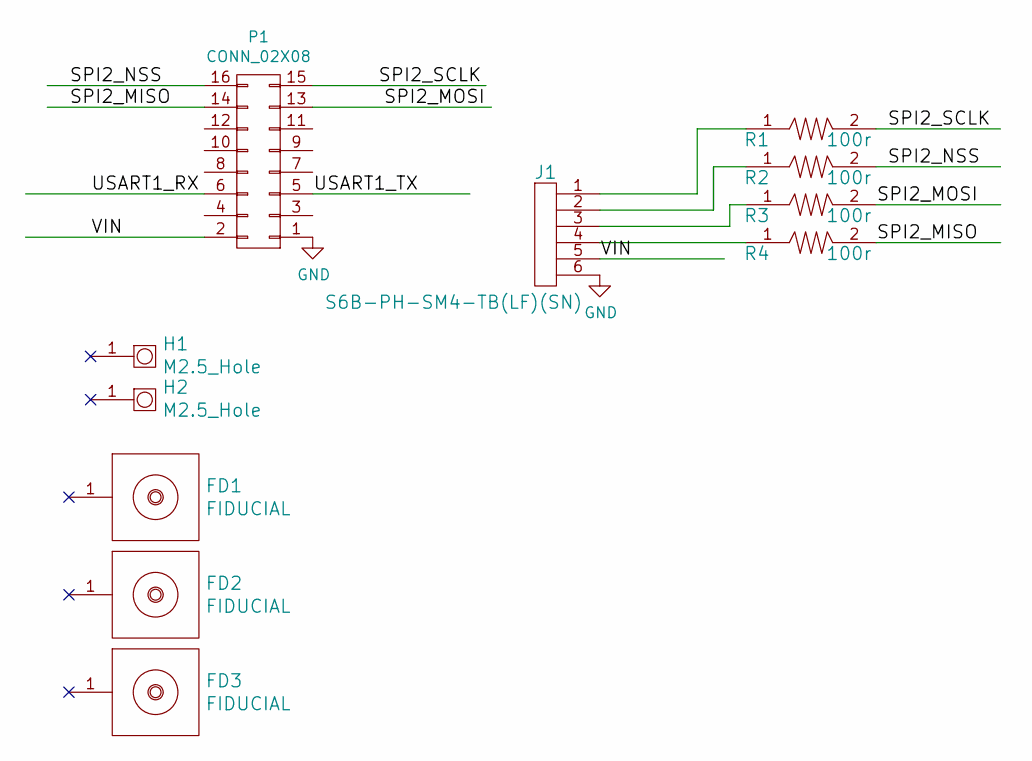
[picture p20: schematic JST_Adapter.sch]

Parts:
FD1, FD2, FD3: FIDUCIAL
H1, H2: M2.5_Hole; M2.5_HOLE
J1: S6B-PH-SM4-TB(LF)(SN); Tolerance N/A; Voltage N/A; MFR# S6B-PH-SM4-TB(LF)(SN)
P1: CONN_02X08; Socket_Strip_Straight_2x08
R1, R2, R3, R4: TNPW0402100RBEED; R0402; Tolerance 0.1%; Voltage N/A; MFR# TNPW0402100RBEED

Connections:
/SPI2_MISO: P1.14, R4.2
/SPI2_MOSI: P1.13, R3.2
/SPI2_NSS: P1.16, R2.2
/SPI2_SCLK: P1.15, R1.2
/USART1_RX: P1.6
/USART1_TX: P1.5
/VIN: J1.5, P1.2
GND: J1.6, P1.1
unnamed: J1.1, R1.1
unnamed: J1.2, R2.1
unnamed: J1.3, R3.1
unnamed: J1.4, R4.1

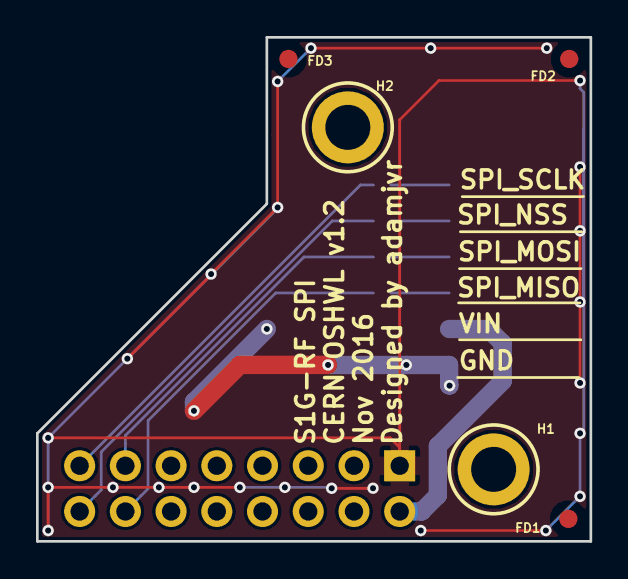
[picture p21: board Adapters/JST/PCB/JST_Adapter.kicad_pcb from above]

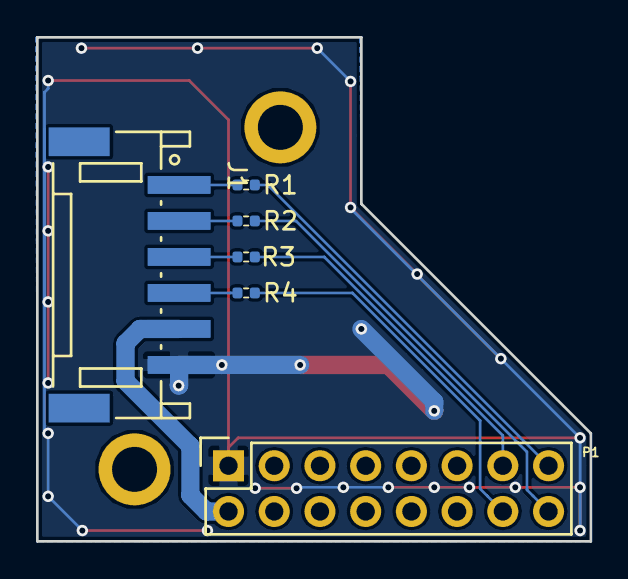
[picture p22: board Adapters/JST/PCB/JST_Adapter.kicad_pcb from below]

Board: 2 copper layers, 30.8 x 28.0 mm, 11 parts (6 on the bottom side), 10 nets.

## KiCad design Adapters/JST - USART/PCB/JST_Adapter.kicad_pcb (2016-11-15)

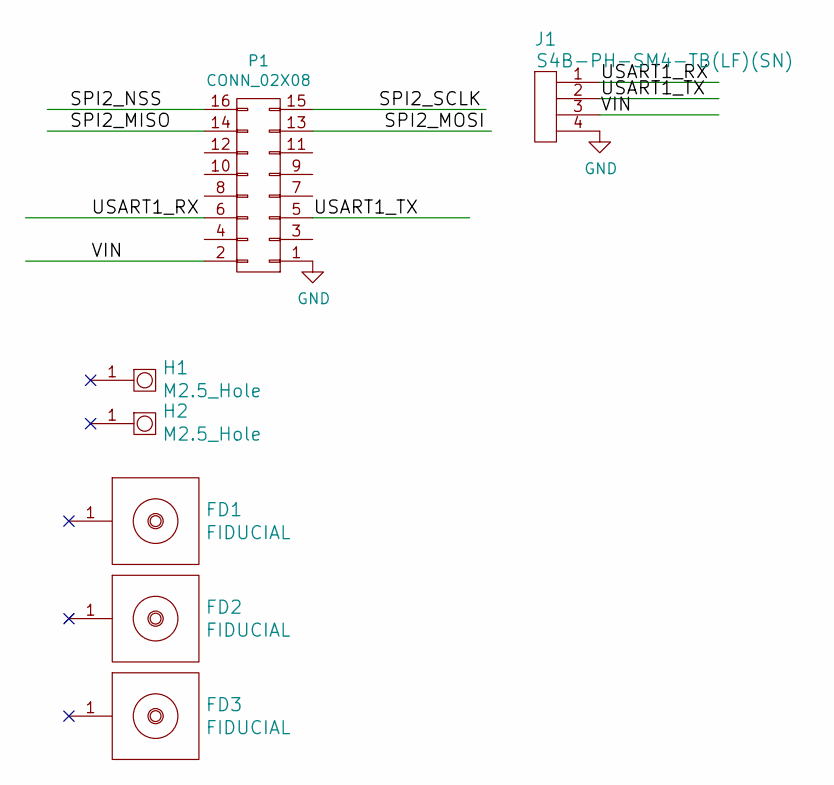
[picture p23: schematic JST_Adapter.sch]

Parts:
FD1, FD2, FD3: FIDUCIAL
H1, H2: M2.5_Hole; M2.5_HOLE
J1: S4B-PH-SM4-TB(LF)(SN); Tolerance N/A; Voltage N/A; MFR# S4B-PH-SM4-TB(LF)(SN)
P1: CONN_02X08; Socket_Strip_Straight_2x08

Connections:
/SPI2_MISO: P1.14
/SPI2_MOSI: P1.13
/SPI2_NSS: P1.16
/SPI2_SCLK: P1.15
/USART1_RX: J1.1, P1.6
/USART1_TX: J1.2, P1.5
/VIN: J1.3, P1.2
GND: J1.4, P1.1

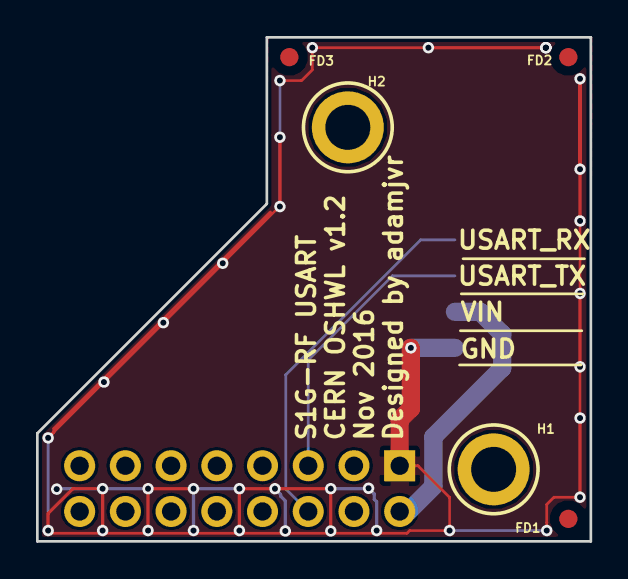
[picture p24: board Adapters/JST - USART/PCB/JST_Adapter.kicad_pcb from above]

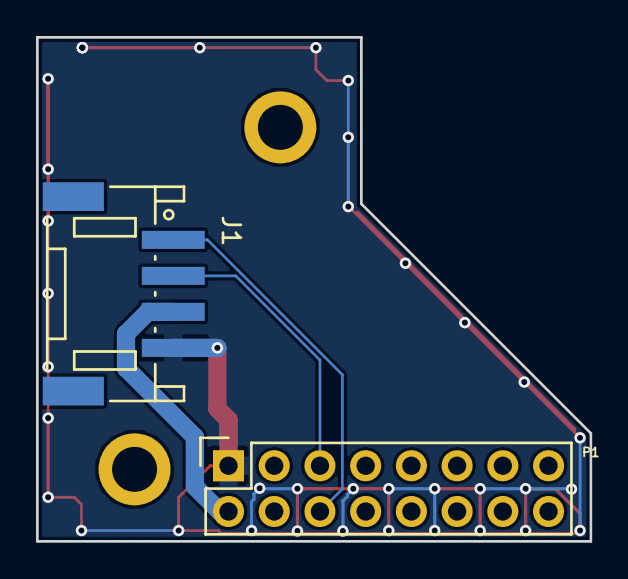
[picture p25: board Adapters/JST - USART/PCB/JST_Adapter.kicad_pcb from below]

Board: 2 copper layers, 30.8 x 28.0 mm, 7 parts (2 on the bottom side), 4 nets.

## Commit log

2016-10-30 Initial Commit
    Schematic and Kicad project created for the three different versions of
    the module.
    [S1G_Mod_433.kicad_pcb, S1G_Mod_433.sch, S1G_Mod_868.kicad_pcb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]
2016-10-31 868MHZ
    Significant progress made with 868MHZ schematic, near complete just
    researching the output section more before commiting to component and
    circuit choices.
    [S1G_Mod_868.sch]
2016-10-31 PCB Created
    PCB created and placemetn started. Going to be a more robust
    implementatinn of XBee pro but bigger formfactor. going to require dual
    antennas or external mixrer (perhaps another PCB "? )
    [S1G_Mod_868.sch, S1G_Mod_868_CMB.kicad_pcb, S1G_Mod_868_CMB.sch]
2016-11-07 Progress and reorganized
    project reorganized separate PA/LNA version near done, added an M0+ MCU.
    [S1G_Mod_433.kicad_pcb, S1G_Mod_433.sch, S1G_Mod_868.kicad_pcb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]
2016-11-08 Change and Progress
    connecotrs change to SMA, implemented combined PA/LNA match, currently
    working on that version as primary. PCB components are placed and board
    size is almost set.
    [S1G_Mod_868.kicad_pcb, S1G_Mod_868.sch, S1G_Mod_868_CMB.kicad_pcb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]
2016-11-10 RF Shield and more progress
    Adding an RF shield to the combined implementation of the 915MHZ version
    of S1G. Also experimenting with differnt connectors and what not.
    [S1G_Mod_868.kicad_pcb, S1G_Mod_868.sch, STM32L052K8T6-MCU.sch]
2016-11-10 First pass on PCB
    First pass on PCB completed. PCB_868_900_Combined is the folder for the
    finished rev.
    [S1G_Mod_868.kicad_pcb, S1G_Mod_868.sch, STM32L052K8T6-MCU.sch]
2016-11-10 Cleaner routing
    Cleaned up routing and improved copper pours in the RF section. Need to
    do a bit more research on how much fill is necessary with a 4 layer
    board.
    [S1G_Mod_868.kicad_pcb]
2016-11-11 License added and dedicated PA/LNA Match
    Working on the separate PA/LNA match version. also added cern license
    [S1G_Mod_868.kicad_pcb, S1G_Mod_868.sch, STM32L052K8T6-MCU.sch]
2016-11-11 Progress
    Significant progress on the separate PA/LNA matchj implementation.
    Formfactor has been devised and is similar to the combined version , so
    they go together well. Component placement is mostly complete and board
    outline solidified.
    [S1G_Mod_868.kicad_pcb]
2016-11-11 Separate PA/LNA first pass
    first pass on PCB complete !
    [S1G_Mod_868.kicad_pcb]
2016-11-12 PCBs Tweaked A lot
    PCBs have been tweaked. The separate implementation has been finished
    but also has GPIOs from the MCU broken out to the connector, same for
    the combined implementation. Both boards now have power indication LEDs
    (red).
    [S1G_Mod_868.kicad_pcb, S1G_Mod_868.sch, STM32L052K8T6-MCU.sch]
2016-11-14 Grounding and Adapter
    Grounding changed on both versions of the 915MHZ/868MHZ versions of the
    radio both the combined and separate antenna versions. Also an adapter
    is being developed for alternative connection options.
    [JST_Adapter.kicad_pcb, JST_Adapter.sch, S1G_Mod_868.kicad_pcb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]
2016-11-14 adapter finished
    finished adapter
    [JST_Adapter.kicad_pcb, JST_Adapter.sch]
2016-11-14 Via Stitching
    Ground pour stiching applied to the combined PA/LNA match version of the
    915MHZ radio. All ground pours and layers are now stiched together
    effectively.
    [JST_Adapter.kicad_pcb, JST_Adapter.stp, S1G_Mod_868.kicad_pcb]
2016-11-14 Separate Antenna Via Stiching
    The S1G implementation with separate antennas and matching circuitry has
    been thoroughly stiched with vias linking all ground pours to the
    internal plane with a significant amunt of connection points.
    [S1G_Mod_868.kicad_pcb]
2016-11-14 Additional GPIO
    Two additional GPIO pins from the STM32L0 have been added to the
    connector, now there is a signal on every pin. The connector component
    has been replaced with one that has a STEP 3D model for proper 3D model
    exporting from KiCAD for enclosure design. This has been done to both
    versions of the radio.
    [S1G_Mod_868.kicad_pcb, S1G_Mod_868.sch, STM32L052K8T6-MCU.sch]
2016-11-15 Adapters
    Adapter ended up being too large. So I split it into two separate
    adapters one for SPI and one for USART over JST connectors. SPI board
    has 100 ohm inline resistors for EMI and impedance matching in case the
    driving device lacks these internally or on its board. Additional
    Fudicials added to the combined implementation.
    [JST_Adapter.kicad_pcb, JST_Adapter.sch, JST_Adapter.stp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]
2016-11-15 LDO and Pwr LEd
    Power LED added to combined radio and LDO section revamped.
    [S1G_Mod_868.kicad_pcb, S1G_Mod_868.sch, STM32L052K8T6-MCU.sch]
2016-11-15 More LDO
    LDO section on separate antenna version retooled to be more like the
    combined antenna version. Added additional fudicials on the bottom.
    [S1G_Mod_868.kicad_pcb, S1G_Mod_868.sch, STM32L052K8T6-MCU.sch]
2016-11-15 SPI Resistors
    Added 100 ohm inline resistors with SPI line and IRQ signal between
    ADF7023 and STM32L0 on the separate antenna implementation.
    [S1G_Mod_868.kicad_pcb, S1G_Mod_868.sch]
2016-11-15 SPI Resistors
    SPI resistors added to combined antenna implementation.
    [S1G_Mod_868.kicad_pcb, S1G_Mod_868.sch, STM32L052K8T6-MCU.sch]
2016-11-15 DRC Check
    DRC check run and all errors cleared on separate anatenna implmentation.
    Nearing time to fabricate.
    [S1G_Mod_868.kicad_pcb]
2016-11-15 DRC Check Combined
    DRC Check run on combined implementation. All errors cleared,
    fabrication soon.
    [S1G_Mod_868.kicad_pcb]
2016-11-16 Readme
    Readme updated and boms exported.
    [S1G_Mod_868.kicad_pcb, S1G_Mod_868_combined.csv, S1G_Mod_868_separate.csv]
2016-11-16 Readme
    Readme updated with images.
    [JST_Adapter.kicad_pcb]
2016-11-17 USB VDD
    Found schematic bug, USB VDD was not tied to 3V3 supply or applied a
    bypass cap, this has been resolved in both implementations of the S1G.
    STM32L0 program manual added to the datasheets collection for the
    project. Schematic PDFs updated.
    [S1G_Mod_868.kicad_pcb, S1G_Mod_868.sch, STM32L052K8T6-MCU.sch]
2016-11-20 More Stitching and readme
    Added more via stitching to separate RX/TX implementation. More vias
    near the pin connector like the combined version. Also added a link to
    the firmware repo on the readme.
    [S1G_Mod_868.kicad_pcb]
2016-12-06 0.22uF cap
    0.22uF cap replaced with 0402 part instead of the massive 0603 part.
    [S1G_Mod_868.kicad_pcb, S1G_Mod_868.sch]
2017-07-16 Radio Reference Schematic Errors
    Some errors transcribing ADI's reference shcematic. 0.22uF caps added to
    pins that needed it etc.
    [S1G_Mod_868.kicad_pcb, S1G_Mod_868.sch, STM32L052K8T6-MCU.sch]
2017-07-27 PDF
    schematic exported as color PDF for review
    [S1G_Mod_868.kicad_pcb, S1G_Mod_868.sch, STM32L052K8T6-MCU.sch]
